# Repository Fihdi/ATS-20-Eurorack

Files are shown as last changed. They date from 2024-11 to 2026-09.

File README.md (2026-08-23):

# 10hp Radio Module (WORK IN PROGRESS)

**UPDATE 23rd August: Reworking this module by combining the A- and B-Board**

An ATS-20 Radio port in 3U height. Jumpers on the PCB lets the device be used as an Eurorack module or as a standalone all-band receiver.

A regular 12VDC wall wart or a 9V battery can be used for standalone usage.

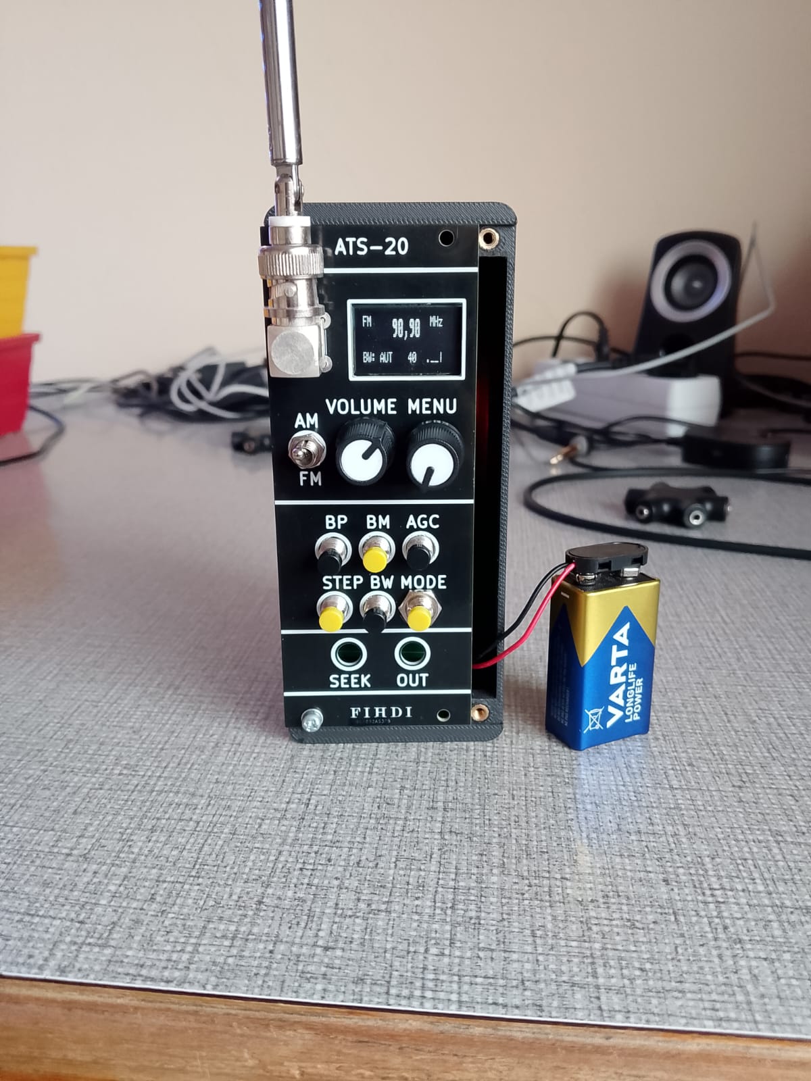
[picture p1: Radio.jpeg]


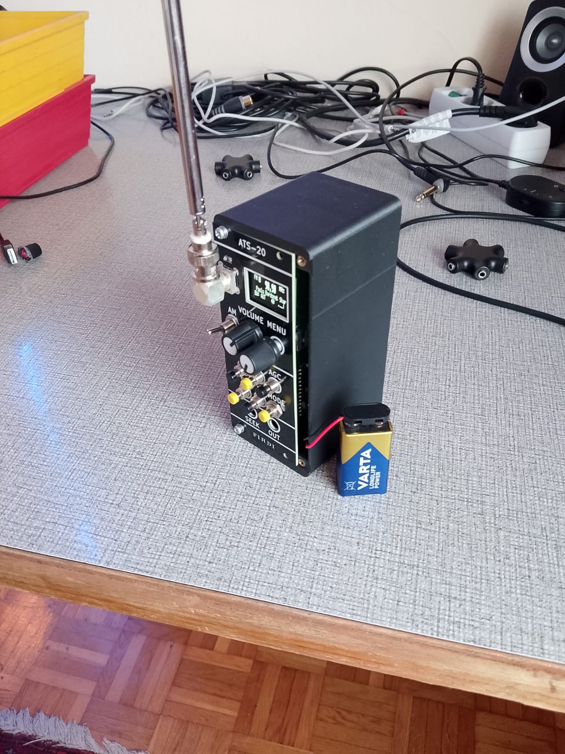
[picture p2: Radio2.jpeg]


The module that you see in the picture above is using circuit boards that were fabricated by [PCBWay](https://www.pcbway.com/) They have excellent build quality and I can recommend using their service to build your own projects! I used the "Black" option for the soldermask and the surface has very deep and glossy black finish, which looks amazing, they also have an option for a "Matte Black" finish which I will try next time. Thank you PCBWay for sponsoring this module. 
This is the first project that features a small OLED display, and thus the first project where I cut out a square section from the frontplate. This worked out really well and the corners are clean 90 degrees with no rounding. They are also having a 3D printing service, which means you can order the boards and the case for this radio all in one place.

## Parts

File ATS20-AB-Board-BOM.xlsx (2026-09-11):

 |  |  | ATS-20 AB-Board-BOM
Item # | *Designator | *Qty | Manufacturer | *Mfg Part # | Description / Value | *Package/Footprint | Type | Your Instructions / Notes
1 | A1 | 1 |  |  | Arduino_Nano_Every | Module:Arduino_Nano |  | DNP
2 | C1,C11,C12,C14,C101,C103 | 6 |  | C28323 | 1u | Capacitor_SMD:C_0805_2012Metric
3 | C2,C13 | 2 |  | C2836442 | 100u | Capacitor_SMD:C_Elec_6.3x7.7
4 | C3,C6 | 2 |  | C15850 | 10u | Capacitor_SMD:C_0805_2012Metric
5 | C4,C102 | 2 |  | C49678 | 100n | Capacitor_SMD:C_0805_2012Metric
6 | C5 | 1 |  | C2858856 | 470u | Capacitor_SMD:C_Elec_6.3x7.7
7 | C7 | 1 |  | C94121 | 1nF | Capacitor_SMD:C_0805_2012Metric
8 | C8 | 1 |  | C5375825 | 470nF | Capacitor_SMD:C_0805_2012Metric
9 | C9,C10 | 2 |  | C376875 | 22pF | Capacitor_SMD:C_0805_2012Metric
10 | D1,D2,D14,D15 | 4 |  | C917117 | 1N4148 | Diode_SMD:D_SOD-323_HandSoldering
11 | J1 | 1 |  |  | Conn_02x05_Odd_Even | Connector_IDC:IDC-Header_2x05_P2.54mm_Vertical |  | DNP
12 | J2 | 1 |  |  | AudioJack3 | Library:StereoTRS |  | DNP
13 | J4 | 1 |  |  | Conn_Coaxial | Library:RS218-4243 |  | DNP
14 | J6 | 1 |  |  | Screw_Terminal_01x02 | TerminalBlock_Phoenix:TerminalBlock_Phoenix_MKDS-1,5-2-5.08_1x02_P5.08mm_Horizontal |  | DNP
15 | J7 | 1 |  |  | Conn_01x04_Pin | Connector_PinSocket_2.54mm:PinSocket_1x04_P2.54mm_Vertical |  | DNP
16 | J9,J10,J13,J15 | 4 |  |  | Conn_01x02_Pin | Connector_PinHeader_2.54mm:PinHeader_1x03_P2.54mm_Vertical |  | DNP
17 | J17 | 1 |  |  | AudioJack2 | Library:MonoTRS |  | DNP
18 | J103 | 1 |  |  | Screw_Terminal_01x02 | TerminalBlock_RND:TerminalBlock_RND_205-00287_1x02_P5.08mm_Horizontal |  | DNP
19 | Q1 | 1 |  | C475630 | BC847 | Package_TO_SOT_SMD:SOT-23
20 | R1,R4,R11,R12 | 4 |  | C2907217 | 100k | Resistor_SMD:R_0805_2012Metric
21 | R2,R6,R13 | 3 |  | C2930202 | 47k | Resistor_SMD:R_0805_2012Metric
22 | R3 | 1 |  | C17414 | 10k | Resistor_SMD:R_0805_2012Metric
23 | R5 | 1 |  | C95781 | 1k | Resistor_SMD:R_0805_2012Metric
24 | R7,R8,R9,R10,R101,R102 | 6 |  | C2907326 | 4k7 | Resistor_SMD:R_0805_2012Metric
25 | RV2 | 1 |  |  | 100k | Potentiometer_THT:Potentiometer_Alpha_RD902F-40-00D_Dual_Vertical |  | DNP
26 | SW1,SW2,SW3,SW4,SW5,SW6 | 6 |  |  | SW_Push | Library:PushButton |  | DNP
27 | SW7 | 1 |  |  | SW_SPDT | Library:Switch |  | DNP
28 | SW8 | 1 |  |  | RotaryEncoder_Switch | Rotary_Encoder:RotaryEncoder_Alps_EC11E-Switch_Vertical_H20mm |  | DNP
29 | U1 | 1 |  | C67473 | TL072 | Package_SO:SOIC-8_3.9x4.9mm_P1.27mm
30 | U2 | 1 |  | C201575 | LM386 | Package_SO:SOIC-8_3.9x4.9mm_P1.27mm |  | DNP
31 | U5 | 1 |  | C20632 | TDA1308 | Package_SO:SOIC-8_3.9x4.9mm_P1.27mm
32 | U6 | 1 |  | C50537368 | LM7805 | Package_TO_SOT_SMD:SOT-223-3_TabPin2
33 | U9 | 1 |  | C2155558 | SI4732 | Package_SO:SOIC-16_4.55x10.3mm_P1.27mm
34 | Y2 | 1 |  | C20617592 | 32.768k | Crystal:Crystal_SMD_3225-4Pin_3.2x2.5mm

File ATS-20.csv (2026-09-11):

Reference | Qty | Value | Footprint | Datasheet
A1 | 1 | Arduino_Nano_Every | Module:Arduino_Nano | https://content.arduino.cc/assets/NANOEveryV3.0_sch.pdf
C1,C11,C12,C14,C101,C103 | 6 | 1u | Capacitor_SMD:C_0805_2012Metric
C2,C13 | 2 | 100u | Capacitor_SMD:C_Elec_6.3x7.7
C3,C6 | 2 | 10u | Capacitor_SMD:C_0805_2012Metric
C4,C102 | 2 | 100n | Capacitor_SMD:C_0805_2012Metric
C5 | 1 | 470u | Capacitor_SMD:C_Elec_6.3x7.7
C7 | 1 | 1nF | Capacitor_SMD:C_0805_2012Metric
C8 | 1 | 470nF | Capacitor_SMD:C_0805_2012Metric
C9,C10 | 2 | 22pF | Capacitor_SMD:C_0805_2012Metric
D1,D2,D14,D15 | 4 | 1N4148 | Diode_SMD:D_SOD-323_HandSoldering
J1 | 1 | Conn_02x05_Odd_Even | Connector_IDC:IDC-Header_2x05_P2.54mm_Vertical
J2 | 1 | AudioJack3 | Library:StereoTRS
J4 | 1 | Conn_Coaxial | Library:RS218-4243
J6 | 1 | Screw_Terminal_01x02 | TerminalBlock_Phoenix:TerminalBlock_Phoenix_MKDS-1,5-2-5.08_1x02_P5.08mm_Horizontal
J7 | 1 | Conn_01x04_Pin | Connector_PinSocket_2.54mm:PinSocket_1x04_P2.54mm_Vertical
J9,J10,J13,J15 | 4 | Conn_01x02_Pin | Connector_PinHeader_2.54mm:PinHeader_1x03_P2.54mm_Vertical
J17 | 1 | AudioJack2 | Library:MonoTRS
J103 | 1 | Screw_Terminal_01x02 | TerminalBlock_RND:TerminalBlock_RND_205-00287_1x02_P5.08mm_Horizontal
Q1 | 1 | BC847 | Package_TO_SOT_SMD:SOT-23 | http://www.infineon.com/dgdl/Infineon-BC847SERIES_BC848SERIES_BC849SERIES_BC850SERIES-DS-v01_01-en.pdf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
R1,R4,R11,R12 | 4 | 100k | Resistor_SMD:R_0805_2012Metric
R2,R6,R13 | 3 | 47k | Resistor_SMD:R_0805_2012Metric
R3 | 1 | 10k | Resistor_SMD:R_0805_2012Metric
R5 | 1 | 1k | Resistor_SMD:R_0805_2012Metric
R7,R8,R9,R10,R101,R102 | 6 | 4k7 | Resistor_SMD:R_0805_2012Metric
RV2 | 1 | 100k | Potentiometer_THT:Potentiometer_Alpha_RD902F-40-00D_Dual_Vertical
SW1,SW2,SW3,SW4,SW5,SW6 | 6 | SW_Push | Library:PushButton
SW7 | 1 | SW_SPDT | Library:Switch
SW8 | 1 | RotaryEncoder_Switch | Rotary_Encoder:RotaryEncoder_Alps_EC11E-Switch_Vertical_H20mm
U1 | 1 | TL072 | Package_SO:SOIC-8_3.9x4.9mm_P1.27mm | http://www.ti.com/lit/ds/symlink/tl071.pdf
U2 | 1 | LM386 | Package_SO:SOIC-8_3.9x4.9mm_P1.27mm | http://www.ti.com/lit/ds/symlink/lm386.pdf
U5 | 1 | TDA1308 | Package_SO:SOIC-8_3.9x4.9mm_P1.27mm | https://www.nxp.com/docs/en/data-sheet/TDA1308.pdf
U6 | 1 | L7805 | Package_TO_SOT_SMD:SOT-223-3_TabPin2 | http://www.st.com/content/ccc/resource/technical/document/datasheet/41/4f/b3/b0/12/d4/47/88/CD00000444.pdf/files/CD00000444.pdf/jcr:content/translations/en.CD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
U9 | 1 | SI4732 | Package_SO:SOIC-16_4.55x10.3mm_P1.27mm
Y2 | 1 | 32.768k | Crystal:Crystal_SMD_3225-4Pin_3.2x2.5mm

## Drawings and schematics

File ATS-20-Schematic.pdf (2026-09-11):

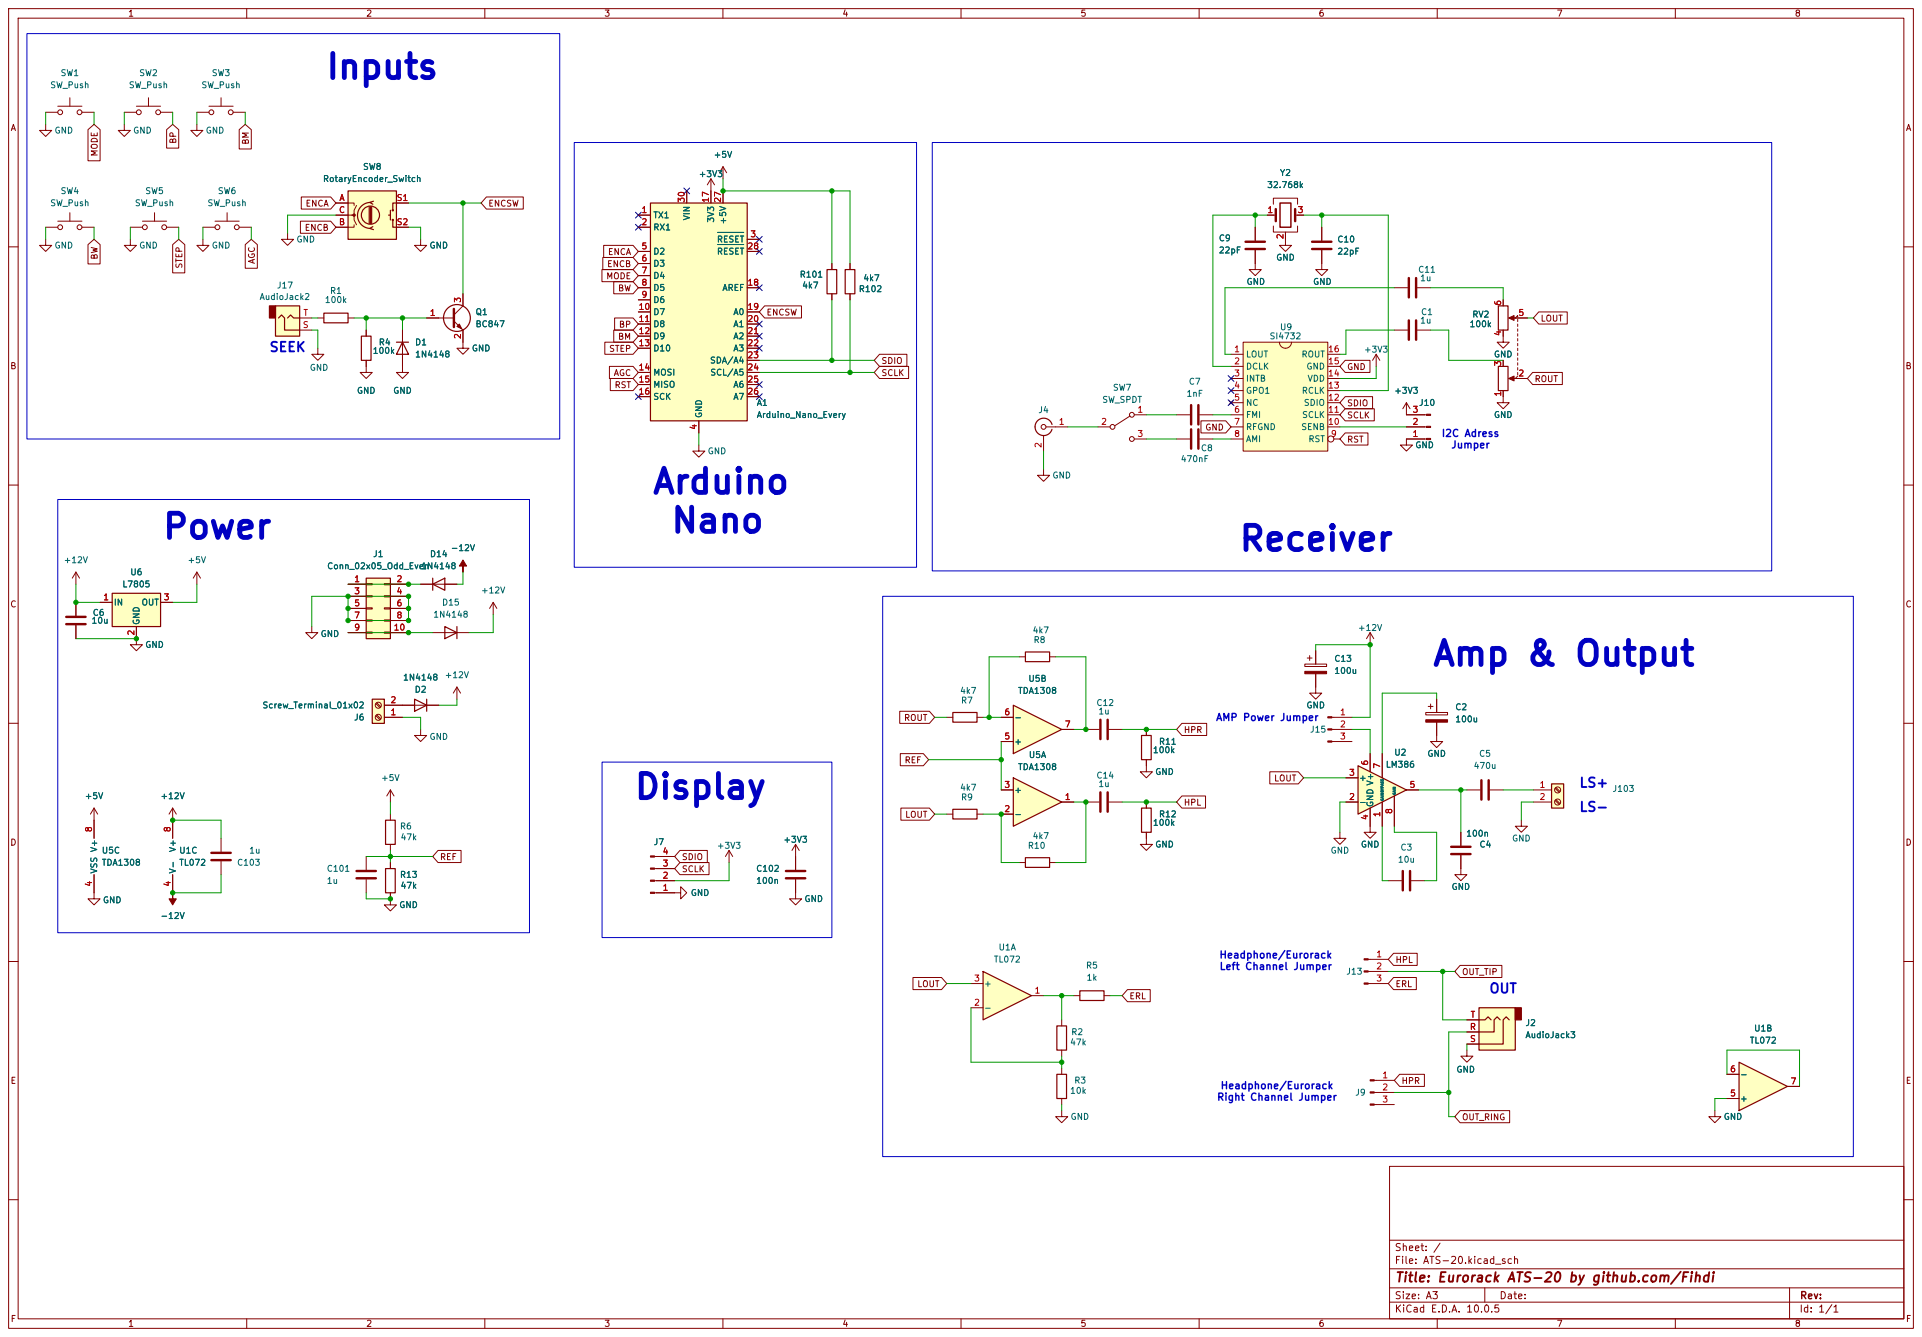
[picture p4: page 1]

SENB 10 SCLK 11 SDIO 12 RCLK 13 VDD 14 GND 15 ROUT 16 U9

Sheet: /
File: ATS-20.kicad_sch
Title: Eurorack ATS-20 by github.com/Fihdi

Size: A3 | Rev: | F Date:
KiCad E.D.A. 10.0.5 | Id: 1/1

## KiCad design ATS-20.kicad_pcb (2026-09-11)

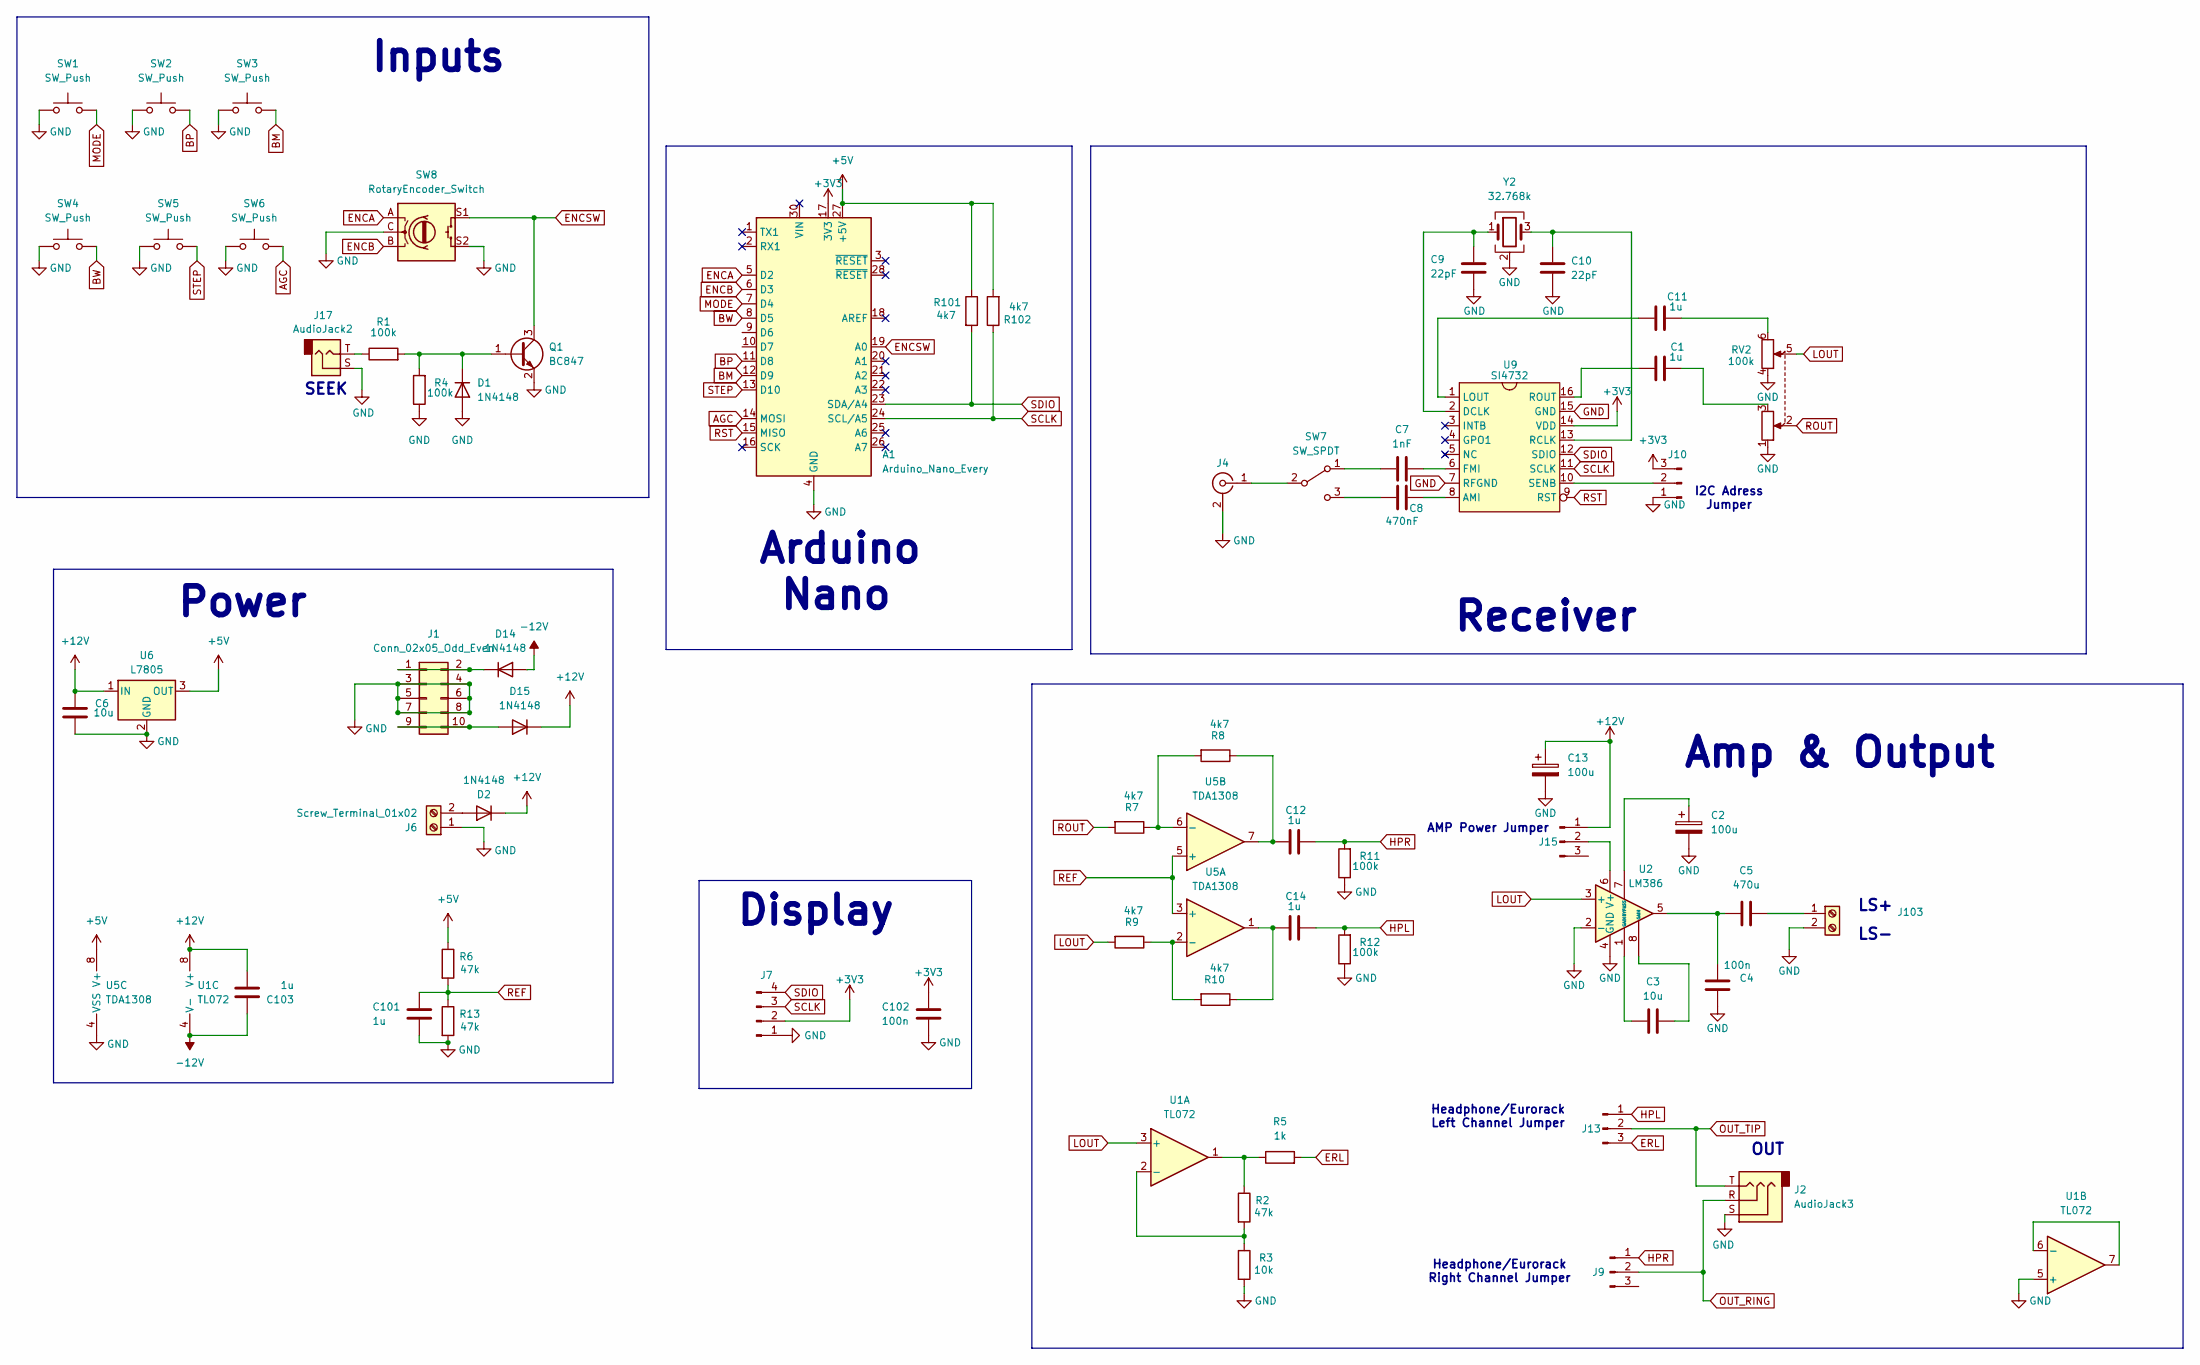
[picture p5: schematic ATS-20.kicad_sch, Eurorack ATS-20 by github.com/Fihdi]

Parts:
A1: Arduino_Nano_Every; Arduino_Nano
C1, C11, C12, C14, C101, C103: 1u; C_0805_2012Metric
C2, C13: 100u; C_Elec_6.3x7.7
C3, C6: 10u; C_0805_2012Metric
C4, C102: 100n; C_0805_2012Metric
C5: 470u; C_Elec_6.3x7.7
C7: 1nF; C_0805_2012Metric
C8: 470nF; C_0805_2012Metric
C9, C10: 22pF; C_0805_2012Metric
D1, D2, D14, D15: 1N4148; D_SOD-323_HandSoldering
J1: Conn_02x05_Odd_Even; IDC-Header_2x05_P2.54mm_Vertical
J2: AudioJack3; StereoTRS
J4: Conn_Coaxial; RS218-4243
J6: Screw_Terminal_01x02; TerminalBlock_Phoenix_MKDS-1,5-2-5.08_1x02_P5.08mm_Horizont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
J7: Conn_01x04_Pin; PinSocket_1x04_P2.54mm_Vertical
J9, J10, J13, J15: Conn_01x02_Pin; PinHeader_1x03_P2.54mm_Vertical
J17: AudioJack2; MonoTRS
J103: Screw_Terminal_01x02; TerminalBlock_RND_205-00287_1x02_P5.08mm_Horizontal
Q1: BC847; SOT-23
R1, R4, R11, R12: 100k; R_0805_2012Metric
R2, R6, R13: 47k; R_0805_2012Metric
R3: 10k; R_0805_2012Metric
R5: 1k; R_0805_2012Metric
R7, R8, R9, R10, R101, R102: 4k7; R_0805_2012Metric
RV2: 100k; Potentiometer_Alpha_RD902F-40-00D_Dual_Vertical
SW1, SW2, SW3, SW4, SW5, SW6: SW_Push; PushButton
SW7: SW_SPDT; Switch
SW8: RotaryEncoder_Switch; RotaryEncoder_Alps_EC11E-Switch_Vertical_H20mm
U1: TL072; SOIC-8_3.9x4.9mm_P1.27mm
U2: LM386; SOIC-8_3.9x4.9mm_P1.27mm
U5: TDA1308; SOIC-8_3.9x4.9mm_P1.27mm
U6: L7805; SOT-223-3_TabPin2
U9: SI4732; SOIC-16_4.55x10.3mm_P1.27mm
Y2: 32.768k; Crystal_SMD_3225-4Pin_3.2x2.5mm

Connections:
+3V3: A1.17 (3V3), C102.2, J7.2, J10.3, U9.14 (VDD)
+5V: A1.27 (+5V), R6.1, R101.1, R102.2, U5.8 (V+), U6.3 (OUT)
+12V: C6.1, C13.1, C103.1, D2.1 (K), D15.1 (K), J15.1, U1.8 (V+), U6.1 (IN)
-12V: C103.2, D14.2 (A), U1.4 (V-)
AGC: A1.14 (MOSI), SW6.2
BM: A1.12 (D9), SW3.2
BP: A1.11 (D8), SW2.2
BW: A1.8 (D5), SW4.2
ENCA: A1.5 (D2), SW8.A
ENCB: A1.6 (D3), SW8.B
ENCSW: A1.19 (A0), Q1.3 (C), SW8.S1
ERL: J13.3, R5.2
GND: A1.4 (GND), A1.29 (GND), C2.2, C4.1, C6.2, C9.2, C10.2, C13.2, C101.1, C102.1, D1.2 (A), J1.3, J1.4, J1.5, J1.6, J1.7, J1.8, J2.S, J4.2 (Ext), J6.1, J7.1, J10.1, J17.S, J103.2, Q1.2 (E), R3.2, R4.1, R11.1, R12.1, R13.2, RV2.1, RV2.4, SW1.1, SW2.1, SW3.1, SW4.1, SW5.1, SW6.1, SW8.C, SW8.S2, U1.5 (+), U2.2 (-), U2.4 (GND), U5.4 (VSS), U6.2 (GND), U9.7 (RFGND), U9.15 (GND), Y2.2 (G), Y2.4 (G)
HPL: C14.2, J13.1, R12.2
HPR: C12.2, J9.1, R11.2
LOUT: R9.2, RV2.5, U1.3 (+), U2.3 (+)
MODE: A1.7 (D4), SW1.2
unnamed: C1.2, RV2.3
unnamed: C3.1, U2.8 (GAIN)
unnamed: C3.2, U2.1 (GAIN)
unnamed: C4.2, C5.2, U2.5
unnamed: C11.2, RV2.6
unnamed: C12.1, R8.1, U5.7
unnamed: C14.1, R10.1, U5.1
unnamed: D1.1 (K), Q1.1 (B), R1.2, R4.2
unnamed: D2.2 (A), J6.2
unnamed: D14.1 (K), J1.1, J1.2
unnamed: D15.2 (A), J1.9, J1.10
unnamed: J4.1 (In), SW7.2 (B)
unnamed: J10.2, U9.10 (SENB)
unnamed: J15.2, U2.6 (V+)
unnamed: J17.T, R1.1
unnamed: C5.1, J103.1
unnamed: R2.1, R5.1, U1.1
unnamed: C7.2, SW7.1 (A)
unnamed: C8.2, SW7.3 (C)
unnamed: R2.2, R3.1, U1.2 (-)
unnamed: U1.6 (-), U1.7
unnamed: C2.1, U2.7 (BYPASS)
unnamed: R9.1, R10.2, U5.2 (-)
unnamed: R7.1, R8.2, U5.6 (-)
unnamed: C8.1, U9.8 (AMI)
unnamed: C9.1, U9.2 (DCLK), Y2.1
unnamed: C7.1, U9.6 (FMI)
unnamed: C11.1, U9.1 (LOUT)
unnamed: C10.1, U9.13 (RCLK), Y2.3
unnamed: C1.1, U9.16 (ROUT)
OUT_RING: J2.R, J9.2
OUT_TIP: J2.T, J13.2
REF: C101.2, R6.2, R13.1, U5.3 (+), U5.5 (+)
ROUT: R7.2, RV2.2
RST: A1.15 (MISO), U9.9 (RST)
SCLK: A1.24 (SCL/A5), J7.3, R102.1, U9.11 (SCLK)
SDIO: A1.23 (SDA/A4), J7.4, R101.2, U9.12 (SDIO)
STEP: A1.13 (D10), SW5.2

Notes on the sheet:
SEEK
Power
OUT
Display
I2C Adress Jumper
Amp & Output
Headphone/Eurorack Left Channel Jumper
Headphone/Eurorack Right Channel Jumper
Arduino Nano
LS-
Inputs
Receiver
LS+
AMP Power Jumper

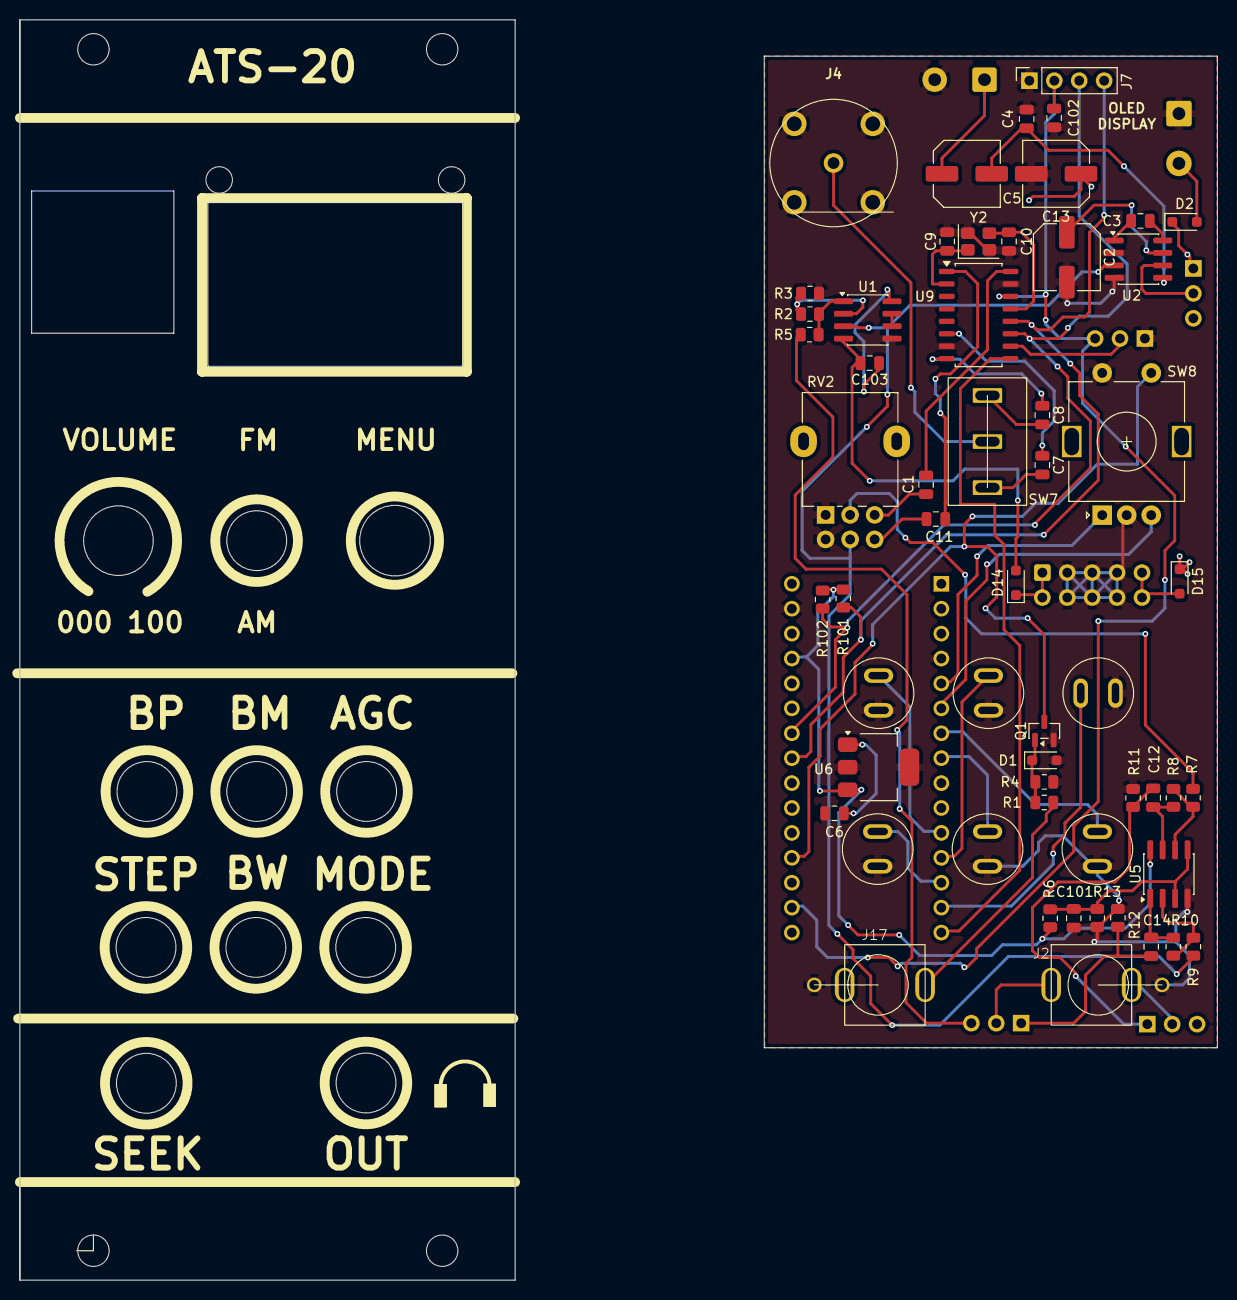
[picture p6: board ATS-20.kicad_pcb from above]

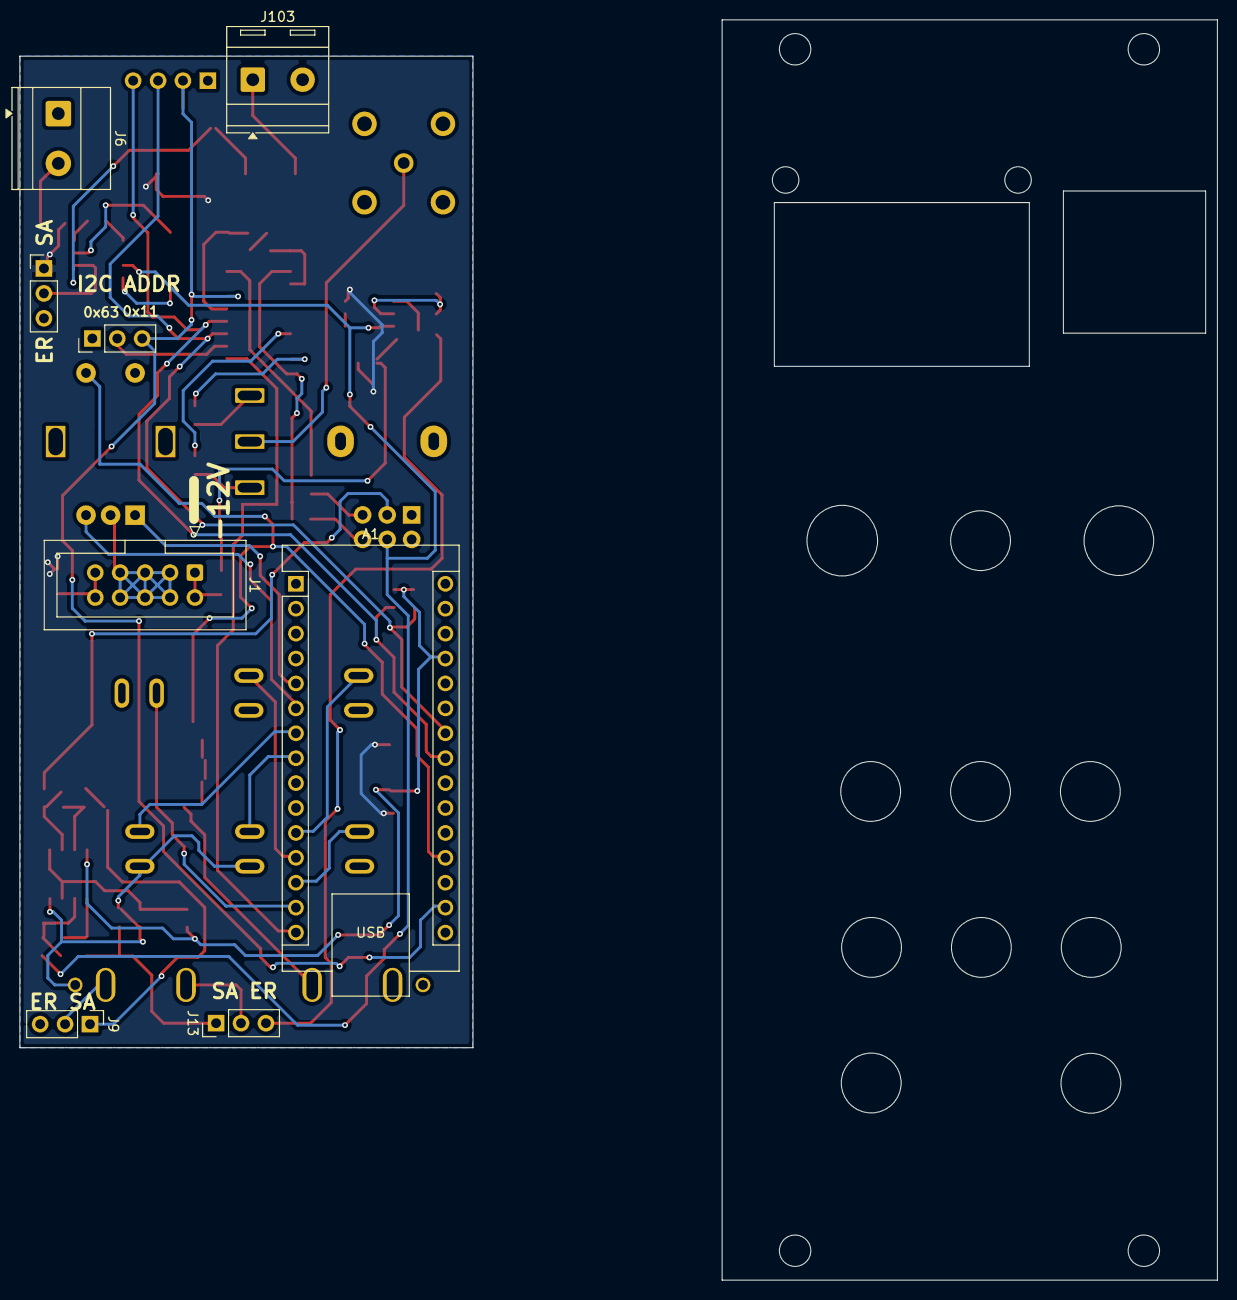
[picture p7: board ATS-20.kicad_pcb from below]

Board: 2 copper layers, 46.2 x 101.1 mm, 64 parts (8 on the bottom side), 55 nets.

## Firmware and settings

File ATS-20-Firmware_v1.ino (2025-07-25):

//DISCLAIMER: Original Code is from https://github.com/pu2clr/SI4735/blob/master/examples/SI47XX_ATS20_ATS20%2B/SI473X_ALL_IN_ONE_OLED_RDS_CHINESE_V9/SI473X_ALL_IN_ONE_OLED_RDS_CHINESE_V9/SI473X_ALL_IN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
/*
  This sketch SHOULD work with the Chinese KIT sold on AliExpress, eBay and Amazon
  The author of this sketch and Arduino Library does not know the seller of this kit and does not have a commercial relationship with any commercial product that uses the Arduino Library.
  It is important you understand that there is no guarantee that this sketch will work correctly in your current product.
  SO, DO NOT TRY IT IF YOU DON'T KNOW WHAT ARE YOU DOING. YOU MUST BE ABLE TO GO BACK TO THE PREVIOUS VERSION IF THIS SKETCH DOES NOT WORK FOR YOU.

  The user interface and commands are different if compared with the original sketch.
  Please, read the user_manual.txt for more details about this sketch before updating your receiver.
  PLEASE, READ THE user_manual.txt FOR MORE DETAILS ABOUT THIS SKETCH BEFORE UPDATING YOUR RECEIVER.

  ATTENTION: Turn your receiver on with the encoder push button pressed at first time to RESET the eeprom content.
  ARDUINO LIBRARIES:
  1) This sketch uses the Rotary Encoder Class implementation from Ben Buxton (the source code is included together with this sketch). You do not need to install it;
  2) Tiny4kOLED Library and TinyOLED-Fonts (on your Arduino IDE, look for this library on Tools->Manage Libraries).
  3) PU2CLR SI4735 Arduino Library (on your Arduino IDE look for this library on Tools->Manage Libraries).

  ABOUT THE EEPROM:

  ATMEL says the lifetime of an EEPROM memory position is about 100,000 writes.
  For this reason, this sketch tries to avoid save unnecessary writes into the eeprom.
  So, the condition to store any status of the receiver is changing the frequency,  bandwidth, volume, band or step  and 10 seconds of inactivity.
  For example, if you switch the band and turn the receiver off immediately, no new information will be written into the eeprom.
  But you wait 10 seconds after changing anything, all new information will be written.

  ABOUT SSB PATCH:

  First of all, it is important to say that the SSB patch content is not part of this library. The paches used here were made available by Mr.
  Vadim Afonkin on his Dropbox repository. It is important to note that the author of this library does not encourage anyone to use the SSB patches
  content for commercial purposes. In other words, this library only supports SSB patches, the patches themselves are not part of this library.

  In this context, a patch is a piece of software used to change the behavior of the SI4735 device.
  There is little information available about patching the SI4735 or Si4732 devices. The following information is the understanding of the author of
  this project and it is not necessarily correct. A patch is executed internally (run by internal MCU) of the device.
  Usually, patches are used to fixes bugs or add improvements and new features of the firmware installed in the internal ROM of the device.
  Patches to the SI473X are distributed in binary form and have to be transferred to the internal RAM of the device by
  the host MCU (in this case Arduino). Since the RAM is volatile memory, the patch stored into the device gets lost when you turn off the system.
  Consequently, the content of the patch has to be transferred again to the device each time after turn on the system or reset the device.

  Wire up on Arduino UNO, Pro mini and SI4735-D60

  | Device name               | Device Pin / Description      |  Arduino Pin  |
  | ----------------          | ----------------------------- | ------------  |
  | Display OLED              |                               |               |
  |                           | SDA                           |     A4        |
  |                           | CLK                           |     A5        |
  |     (*1) SI4735           |                               |               |
  |                           | RESET (pin 15)                |     12        |
  |                           | SDIO (pin 18)                 |     A4        |
  |                           | SCLK (pin 17)                 |     A5        |
  |                           | SEN (pin 16)                  |    GND        |
  |     (*2) Buttons          |                               |               |
  |                           | Switch MODE (AM/LSB/AM)       |      4        |
  |                           | Banddwith                     |      5        |
  |                           | Volume                        |      6        |
  |                           | Custom button 1 (*3)          |      7        |
  |                           | Band                          |      8        |
  |                           | Custom button 2 (*3)          |      9        |
  |                           | Step                          |     10        |
  |                           | AGC / Attentuation            |     11        |
  |                           | VFO/VFO Switch (Encoder)      |     14 / A0   |
  |    Encoder (*4)           |                               |               |
  |                           | A                             |       2       |
  |                           | B                             |       3       |

   1 - You can use the SI4732-A10. Check on the SI4732 package the pins: RESET, SDIO, SCLK and SEN.
   2 - Please, read the file user_manual.txt for more detail.
   3 - You can remove this buttons from your circuit and sketch if you dont want to use them.
   4 - Some encoder devices have pins A and B inverted. So, if the clockwise and counterclockwise directions
       are not correct for you, please, invert the settings for pins A and B.

  Prototype documentation: https://pu2clr.github.io/SI4735/
  PU2CLR Si47XX API documentation: https://pu2clr.github.io/SI4735/extras/apidoc/html/

  Donate 
  If you find this project useful, consider making a donation so that the author of this library can purchase components
  and modules for improvements and testing of this library. 
  Click here to donate: https://www.paypal.com/donate/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

  By Ricardo Lima Caratti, April  2021.
  Improved by EFWob (https://github.com/EFWob) Jan 2022.

*/

#define DEBUG  // Comment/uncomment for disabling/enabling debug output on Serial
//#define DEBUG_BUTTONS_ONLY  // If defined (in addition to DEBUG), just do DEBUG output for Buttons (radio will not play at all)

#include <SI4735.h>
#include <EEPROM.h>
#include <Tiny4kOLED.h>
#include <font8x16atari.h>  // Please, install the TinyOLED-Fonts library
#include "Rotary.h"
#include "SimpleButton.h"

#include <patch_ssb_compressed.h>  // Compressed SSB patch version (saving almost 1KB)

const uint16_t size_content = sizeof ssb_patch_content;  // See ssb_patch_content.h
const uint16_t cmd_0x15_size = sizeof cmd_0x15;          // Array of lines where the 0x15 command occurs in the patch content.

#define FM_BAND_TYPE 0
#define MW_BAND_TYPE 1
#define SW_BAND_TYPE 2
#define LW_BAND_TYPE 3

// OLED Diaplay constants
#define RST_PIN -1  // Define proper RST_PIN if required.

#define RESET_PIN 12

// Enconder PINs - if the clockwise and counterclockwise directions are not correct for you, please, invert this settings.
#define ENCODER_PIN_A 2
#define ENCODER_PIN_B 3

// Buttons controllers
#define MODE_SWITCH 4       // Switch MODE (Am/LSB/USB)
#define BANDWIDTH_BUTTON 5  // Used to select the banddwith.
#define AVC_BUTTON 7        // **** Use thi button to implement a new function
#define BAND_BUTTON 8       // Next band
#define SOFTMUTE_BUTTON 9   // **** Use thi button to implement a new function
#define AGC_BUTTON 11       // Switch AGC ON/OF
#define STEP_BUTTON 10      // Used to select the increment or decrement frequency step (see tabStep)
#define ENCODER_BUTTON 14   // Used to select the enconder control (BFO or VFO) and SEEK function on AM and FM modes

#define MIN_ELAPSED_TIME 100
#define MIN_ELAPSED_RSSI_TIME 150

#define DEFAULT_VOLUME 60  // Volume stays at this value in the software, the volume is controlled by the VOLUME knob only.

#define FM 0
#define LSB 1
#define USB 2
#define AM 3
#define LW 4

#define SSB 1

#define STORE_TIME 10000  // Time of inactivity to make the current receiver status writable (10s / 10000 milliseconds).

const uint8_t app_id = 43;  // Useful to check the EEPROM content before processing useful data
const int eeprom_address = 0;
long storeTime = millis();

const char *bandModeDesc[] = { "FM ", "LSB", "USB", "AM " };
uint8_t currentMode = FM;
uint8_t seekDirection = 1;

bool bfoOn = false;

bool ssbLoaded = false;
bool fmStereo = true;
bool cmdAgcAtt = false;    // if true, the encoder will control the AGC / Attenuation
bool cmdStep = false;      // if true, the encoder will control the step frequency
bool cmdBw = false;        // if true, the encoder will control the bandwidth
bool cmdBand = false;      // if true, the encoder will control the band
bool cmdSoftMute = false;  // if true, the encoder will control the Soft Mute attenuation
bool cmdAvc = false;       // if true, the encoder will control Automatic Volume Control

uint8_t muteVolume = 0;  // restore volume for "un-mute"

long countRSSI = 0;

int currentBFO = 0;

// Button handlers for push buttons/encoder
SimpleButton btn_Bandwidth(BANDWIDTH_BUTTON);
SimpleButton btn_BandUp(BAND_BUTTON);
SimpleButton btn_BandDn(SOFTMUTE_BUTTON);
SimpleButton btn_Encoder(ENCODER_BUTTON);
SimpleButton btn_AGC(AGC_BUTTON);
SimpleButton btn_Step(STEP_BUTTON);
SimpleButton btn_Mode(MODE_SWITCH);



long elapsedRSSI = millis();
//TODO long elapsedButton = millis();

// Encoder control variables
volatile int encoderCount = 0;

// Some variables to check the SI4735 status
uint16_t currentFrequency;
uint16_t previousFrequency;
// uint8_t currentStep = 1;
uint8_t currentBFOStep = 25;

// Datatype to deal with bandwidth on AM, SSB and FM in numerical order.
// Ordering by bandwidth values.
typedef struct
{
  uint8_t idx;       // SI473X device bandwidth index value
  const char *desc;  // bandwidth description
} Bandwidth;

int8_t bwIdxSSB = 4;
Bandwidth bandwidthSSB[] = {
  { 4, "0.5" },  // 0
  { 5, "1.0" },  // 1
  { 0, "1.2" },  // 2
  { 1, "2.2" },  // 3
  { 2, "3.0" },  // 4  - default
  { 3, "4.0" }   // 5
};               // 3 = 4kHz

int8_t bwIdxAM = 4;
const int maxFilterAM = 6;
Bandwidth bandwidthAM[] = {
  { 4, "1.0" },  // 0
  { 5, "1.8" },  // 1
  { 3, "2.0" },  // 2
  { 6, "2.5" },  // 3
  { 2, "3.0" },  // 4 - default
  { 1, "4.0" },  // 5
  { 0, "6.0" }   // 6
};

int8_t bwIdxFM = 0;
Bandwidth bandwidthFM[] = {
  { 0, "AUT" },  // Automatic - default
  { 1, "110" },  // Force wide (110 kHz) channel filter.
  { 2, " 84" },
  { 3, " 60" },
  { 4, " 40" }
};

// Atenuação and AGC
int8_t agcIdx = 0;
uint8_t disableAgc = 0;
uint8_t agcNdx = 0;
int8_t smIdx = 8;
int8_t avcIdx = 38;

int tabStep[] = { 1,      // 0
                  5,      // 1
                  9,      // 2
                  10,     // 3
                  50,     // 4
                  100 };  // 5

const int lastStep = (sizeof tabStep / sizeof(int)) - 1;
int idxStep = 3;

/*
   Band data structure
*/
typedef struct
{
  uint8_t bandType;         // Band type (FM, MW or SW)
  uint16_t minimumFreq;     // Minimum frequency of the band
  uint16_t maximumFreq;     // Maximum frequency of the band
  uint16_t currentFreq;     // Default frequency or current frequency
  uint16_t currentStepIdx;  // Idex of tabStep:  Defeult frequency step (See tabStep)
  int8_t bandwidthIdx;      // Index of the table bandwidthFM, bandwidthAM or bandwidthSSB;
} Band;

/*
   Band table
   YOU CAN CONFIGURE YOUR OWN BAND PLAN. Be guided by the comments.
   To add a new band, all you have to do is insert a new line in the table below. No extra code will be needed.
   You can remove a band by deleting a line if you do not want a given band.
   Also, you can change the parameters of the band.
   ATTENTION: You have to RESET the eeprom after adding or removing a line of this table.
              Turn your receiver on with the encoder push button pressed at first time to RESET the eeprom content.
*/
Band band[] = {
  { LW_BAND_TYPE, 100, 510, 300, 0, 4 },
  { MW_BAND_TYPE, 520, 1720, 810, 3, 4 },    // AM/MW from 520 to 1720kHz; default 810kHz; default step frequency index is 3 (10kHz); default bandwidth index is 4 (3kHz)
  { MW_BAND_TYPE, 531, 1701, 783, 2, 4 },    // MW for Europe, Africa and Asia
  { SW_BAND_TYPE, 1700, 3500, 1900, 0, 4 },  // 160 meters
  { SW_BAND_TYPE, 3500, 4500, 3700, 0, 5 },  // 80 meters
  { SW_BAND_TYPE, 4500, 5600, 4850, 1, 4 },
  { SW_BAND_TYPE, 5600, 6800, 6000, 1, 4 },
  { SW_BAND_TYPE, 6800, 7300, 7100, 0, 4 },  // 40 meters
  { SW_BAND_TYPE, 7200, 8500, 7200, 1, 4 },  // 41 meters
  { SW_BAND_TYPE, 8500, 10000, 9600, 1, 4 },
  { SW_BAND_TYPE, 10000, 11200, 10100, 0, 4 },  // 30 meters
  { SW_BAND_TYPE, 11200, 12500, 11940, 1, 4 },
  { SW_BAND_TYPE, 13400, 13900, 13600, 1, 4 },
  { SW_BAND_TYPE, 14000, 14500, 14200, 0, 4 },  // 20 meters
  { SW_BAND_TYPE, 15000, 15900, 15300, 1, 4 },
  { SW_BAND_TYPE, 17200, 17900, 17600, 1, 4 },
  { SW_BAND_TYPE, 18000, 18300, 18100, 0, 4 },  // 17 meters
  { SW_BAND_TYPE, 21000, 21400, 21200, 0, 4 },  // 15 mters
  { SW_BAND_TYPE, 21400, 21900, 21500, 1, 4 },  // 13 mters
  { SW_BAND_TYPE, 24890, 26200, 24940, 0, 4 },  // 12 meters
  { SW_BAND_TYPE, 26200, 28000, 27500, 0, 4 },  // CB band (11 meters)
  { SW_BAND_TYPE, 28000, 30000, 28400, 0, 4 },  // 10 meters
  { FM_BAND_TYPE, 6400, 8400, 7000, 3, 0 },     // FM from 64 to 84MHz; default 70MHz; default step frequency index is 3; default bandwidth index AUTO
  { FM_BAND_TYPE, 8400, 10800, 10570, 3, 0 }
};

const int lastBand = (sizeof band / sizeof(Band)) - 1;
int bandIdx = 1;

uint8_t rssi = 0;
uint8_t stereo = 1;
uint8_t volume = DEFAULT_VOLUME;

// Devices class declarations
Rotary encoder = Rotary(ENCODER_PIN_A, ENCODER_PIN_B);
SI4735 si4735;

void setup() {

#ifdef DEBUG
  Serial.begin(115200);
#ifdef DEBUG_BUTTONS_ONLY
  return;
#endif
#endif
  // Encoder pins
  pinMode(ENCODER_PIN_A, INPUT_PULLUP);
  pinMode(ENCODER_PIN_B, INPUT_PULLUP);

  oled.begin();
  oled.clear();
  oled.on();
  oled.setFont(FONT6X8);

  // Splash - Change orit for your introduction text or remove the splash code.
  oled.setCursor(40, 0);
  oled.print("SI473X");
  oled.setCursor(20, 1);
  oled.print("Arduino Library");
  delay(100);
  oled.setCursor(15, 2);
  oled.print("All in One Radio");
  delay(100);
  oled.setCursor(10, 3);
  oled.print("V3.0.8-By PU2CLR");
  delay(1000);
  // end Splash

  // If you want to reset the eeprom, keep the VOLUME_UP button pressed during statup
  if (digitalRead(ENCODER_BUTTON) == LOW) {
    oled.clear();
    EEPROM.write(eeprom_address, 0);
    oled.setCursor(0, 0);
    oled.print("EEPROM RESETED");
    delay(2000);
    oled.clear();
  }

  // Encoder interrupt
  attachInterrupt(digitalPinToInterrupt(ENCODER_PIN_A), rotaryEncoder, CHANGE);
  attachInterrupt(digitalPinToInterrupt(ENCODER_PIN_B), rotaryEncoder, CHANGE);

  si4735.getDeviceI2CAddress(RESET_PIN);  // Looks for the I2C bus address and set it.  Returns 0 if error

  si4735.setup(RESET_PIN, MW_BAND_TYPE);  //
  si4735.setAvcAmMaxGain(48);             // Sets the maximum gain for automatic volume control on AM/SSB mode (between 12 and 90dB)

  delay(500);

  // Checking the EEPROM content
  if (EEPROM.read(eeprom_address) == app_id) {
    readAllReceiverInformation();
  }

  // Set up the radio for the current band (see index table variable bandIdx )
  useBand();

  currentFrequency = previousFrequency = si4735.getFrequency();

  si4735.setVolume(DEFAULT_VOLUME);
  oled.clear();
  showStatus();
}
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
void loop() {
#if defined(DEBUG) && defined(DEBUG_BUTTONS_ONLY)
  btn_BandUp.checkEvent(buttonEvent);
  btn_BandDn.checkEvent(buttonEvent);
  btn_VolumeUp.checkEvent(buttonEvent);
  btn_VolumeDn.checkEvent(buttonEvent);
  btn_Bandwidth.checkEvent(buttonEvent);
  btn_AGC.checkEvent(buttonEvent);
  btn_Step.checkEvent(buttonEvent);
  btn_Mode.checkEvent(buttonEvent);
  btn_Encoder.checkEvent(buttonEvent);
  return;
#endif
  // Check if the encoder has moved.
  if (encoderCount != 0) {
    if (cmdVolume)
      doVolume(encoderCount);
    else if (cmdAgcAtt)
      doAttenuation(encoderCount);
    else if (cmdStep)
      doStep(encoderCount);
    else if (cmdBw)
      doBandwidth(encoderCount);
    else if (cmdSoftMute)
      doSoftMute(encoderCount);
    else if (cmdAvc)
      doAvc(encoderCount);
    else if (cmdBand) {
      if (encoderCount == 1)
        bandUp();
      else
        bandDown();
    } else if (bfoOn) {
      currentBFO = (encoderCount == 1) ? (currentBFO + currentBFOStep) : (currentBFO - currentBFOStep);
      si4735.setSSBBfo(currentBFO);
      previousFrequency = 0;  // Forces eeprom update
      showBFO();
    } else {
      if (encoderCount == 1) {
        si4735.frequencyUp();
        seekDirection = 1;
      } else {
        si4735.frequencyDown();
        seekDirection = 0;
      }
      // Show the current frequency only if it has changed
      currentFrequency = si4735.getFrequency();
      showFrequency();
    }
    encoderCount = 0;
    resetEepromDelay();  // if you moved the encoder, something was changed
    elapsedRSSI = millis();
    countRSSI = 0;
  }

  // Check button commands
  // check if some button is pressed
  // Shortpress-Events are handled direct, longpress-Events by the specific "event-handler" (the callback function passed to
  // checkEvent
  // If buttonEvent is used as callback, there is no specific functionality attached to longpress, but info is logged on Serial
  // if the flag "DEBUG" is defined (see above)

  if (BUTTONEVENT_SHORTPRESS == btn_Bandwidth.checkEvent(bandwidthEvent)) {
    cmdBw = !cmdBw;
    disableCommand(&cmdBw, cmdBw, showBandwidth);
  }
  if (BUTTONEVENT_SHORTPRESS == btn_BandUp.checkEvent(bandEvent)) {
    cmdBand = !cmdBand;
    disableCommand(&cmdBand, cmdBand, showBandDesc);
  }
  if (BUTTONEVENT_SHORTPRESS == btn_BandDn.checkEvent(bandEvent)) {
    if (currentMode != FM) {
      cmdSoftMute = !cmdSoftMute;
      disableCommand(&cmdSoftMute, cmdSoftMute, showSoftMute);
    }
  }
  if (BUTTONEVENT_SHORTPRESS == btn_VolumeUp.checkEvent(volumeEvent)) {
    cmdVolume = !cmdVolume;
    disableCommand(&cmdVolume, cmdVolume, showVolume);
  }
  if (BUTTONEVENT_SHORTPRESS == btn_VolumeDn.checkEvent(volumeEvent)) {
    if (currentMode != FM) {
      cmdAvc = !cmdAvc;
      disableCommand(&cmdAvc, cmdAvc, showAvc);
    }
  }
  if (BUTTONEVENT_SHORTPRESS == btn_Encoder.checkEvent(encoderEvent)) {
    if (currentMode == LSB || currentMode == USB) {
      bfoOn = !bfoOn;
      if (bfoOn)
        showBFO();
      showStatus();
      disableCommand(NULL, false, NULL);  // disable all command buttons
    } else if (currentMode == FM || currentMode == AM) {
      // Jumps up or down one space
      if (seekDirection)
        si4735.frequencyUp();
      else
        si4735.frequencyDown();

      si4735.seekStationProgress(showFrequencySeek, checkStopSeeking, seekDirection);
      delay(30);
      if (currentMode == FM) {
        float f = round(si4735.getFrequency() / 10.0);
        currentFrequency = (uint16_t)f * 10;  // adjusts band space from 1 (10kHz) to 10 (100 kHz)
        si4735.setFrequency(currentFrequency);
      } else {
        currentFrequency = si4735.getFrequency();  //
      }
      showFrequency();
    }
  }
  if (BUTTONEVENT_SHORTPRESS == btn_AGC.checkEvent(agcEvent)) {
    if (currentMode != FM) {
      cmdAgcAtt = !cmdAgcAtt;
      disableCommand(&cmdAgcAtt, cmdAgcAtt, showAttenuation);
    }
  }
  if (BUTTONEVENT_SHORTPRESS == btn_Step.checkEvent(stepEvent)) {
    if (currentMode != FM) {
      cmdStep = !cmdStep;
      disableCommand(&cmdStep, cmdStep, showStep);
    }
  }
  if (BUTTONEVENT_SHORTPRESS == btn_Mode.checkEvent(modeEvent)) {
    if (currentMode != FM) {
      if (currentMode == AM) {
        // If you were in AM mode, it is necessary to load SSB patch (avery time)
        loadSSB();
        currentMode = LSB;
      } else if (currentMode == LSB) {
        currentMode = USB;
      } else if (currentMode == USB) {
        currentMode = AM;
        ssbLoaded = false;
        bfoOn = false;
      }
      // Nothing to do if you are in FM mode
      band[bandIdx].currentFreq = currentFrequency;
      band[bandIdx].currentStepIdx = idxStep;
      useBand();
    }
  }

  // Show RSSI status only if this condition has changed
  if ((millis() - elapsedRSSI) > MIN_ELAPSED_RSSI_TIME * 9) {
    si4735.getCurrentReceivedSignalQuality();
    int aux = si4735.getCurrentRSSI();
    if (rssi != aux) {
      rssi = aux;
      showRSSI();
    }

    if (countRSSI++ > 3) {
      disableCommand(NULL, false, NULL);  // disable all command buttons
      countRSSI = 0;
    }
    elapsedRSSI = millis();
  }

  if (currentMode == FM) {
    checkRDS();
  }

  // Show the current frequency only if it has changed
  if (currentFrequency != previousFrequency) {
    if ((millis() - storeTime) > STORE_TIME) {
      saveAllReceiverInformation();
      storeTime = millis();
      previousFrequency = currentFrequency;
    }
  }
  delay(10);
}

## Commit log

2026-07-23 Fixed two footprints
    [ATS20-B-Board-BOM.xlsx]
2026-11-11 F Board, AB Board fixes
    F-Board: Button mounting holes diameter.
    AB-Board: Loudspeaker amplifier gets signal from Headphone Amplifier output (for buffering)
    Kicad project and Schematics updated, no change to BOM or position files.
